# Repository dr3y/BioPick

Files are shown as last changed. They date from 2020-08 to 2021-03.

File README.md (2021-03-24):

# BioPick
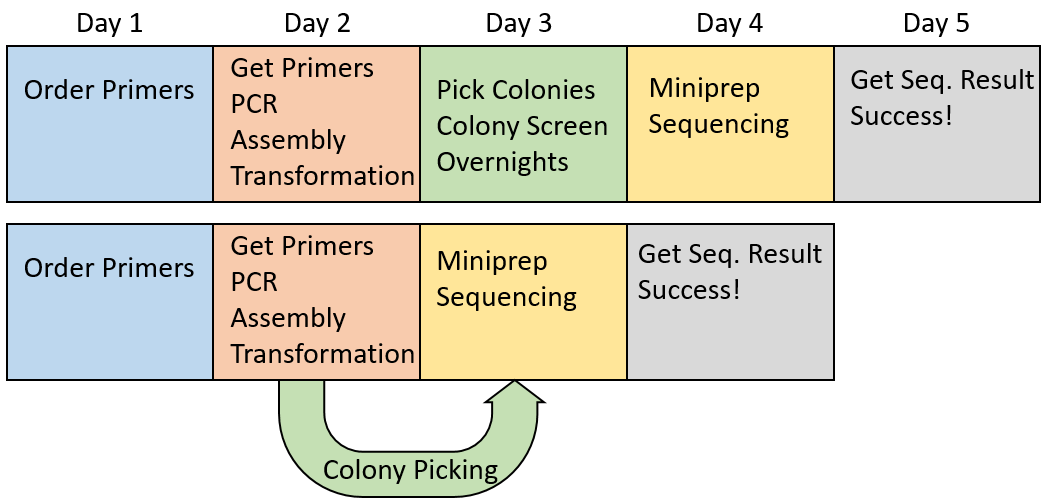
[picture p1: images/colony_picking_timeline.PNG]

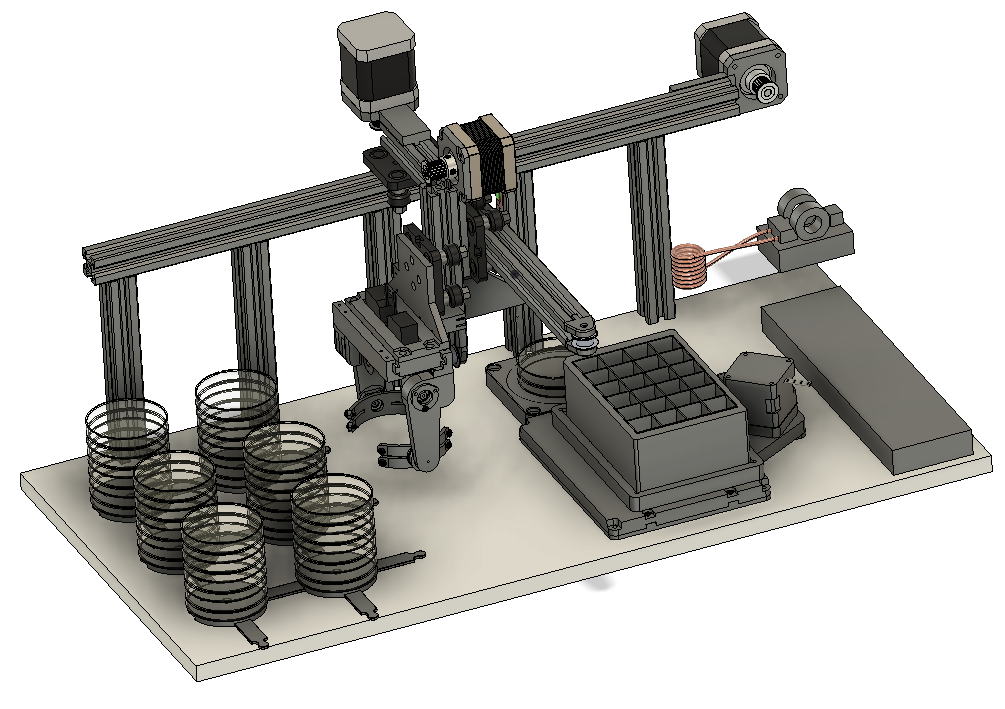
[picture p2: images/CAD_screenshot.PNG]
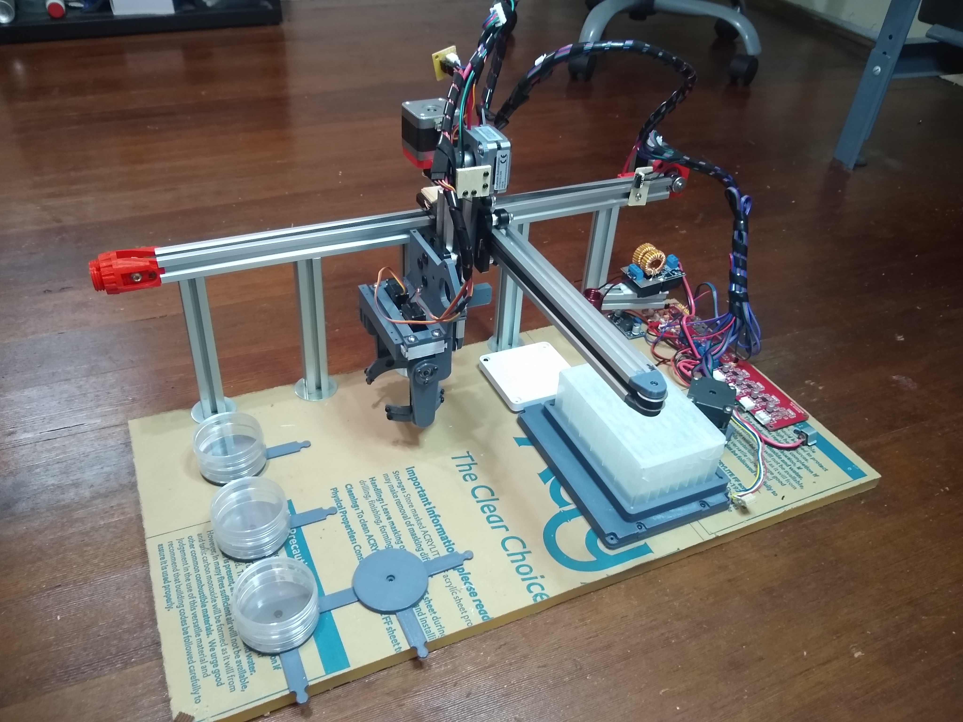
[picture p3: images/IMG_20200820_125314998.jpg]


[video](https://www.youtube.com/watch?v=V8H1xTA8SUk)

BioPick is an open source purpose-built colony picking robot. The idea is to shorten the time from conception to realization of molecular cloning, by allowing automated colony growth and picking as soon as the colonies are grown into liquid culture, to save a day of growth time.
Key features of BioPick are:

1. low profile design
2. multi-plate capacity
3. plate moving and handling capability
4. on board liquid culture shaker
5. metal picking needle that is sterilized by induction heating
6. Off the shelf 3d printer electronics
7. Raspberry Pi camera for colony identification

BioPick is under development so many things can change.
Melzi firmware can be found [here](https://github.com/dr3y/Marlin/tree/Ehoming_test)

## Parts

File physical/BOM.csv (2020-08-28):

name | comment | link | quantity | price | subtotal
V-slot extrusion | 470mm, 310mm, 120mm, 5x140mm | https://www.ebay.com/itm/V-Slot-20x20-Linear-Rail/263747600610 (500mm) | 4 | 5.49
Mini Carriage |  | https://www.amazon.com/Aibecy-Aluminum-Profile-Printer-Accessories/dp/B07SMN97B8/ | 3 | 17.99
inductive heater |  | https://www.amazon.com/Driver-Module-Voltage-Induction-Heating/dp/B01CNM24YM | 1 | 16.7
melzi board | i used a 1.2 board | https://www.amazon.com/MagiDeal-Motherboard-Controller-Mainboard-Control/dp/B0762DXQ8N/ | 1 | 27.99
timing belt and drive pulleys |  | https://www.amazon.com/Zeelo-Timing-Pulley-Meters-Printer/dp/B07XG9JN5B/ | 1 | 12.99
idler pulleys |  | https://www.amazon.com/LICTOP-Aluminum-Timing-Toothless-Printer/dp/B07L9QDVC8 | 1 | 13.99
NEMA17 motor |  | https://www.amazon.com/17HS4401-1-8%C2%B02-Phrase-Universal-Electric-Engraving/dp/B07C1MVTZC/ | 3 | 9.99
low profile NEMA17 motor | i didnt use this one but i think it will work | https://www.amazon.com/Short-Bipolar-Motor-18-4oz-13Ncm/dp/B00PNEQ79Q/ | 1 | 10.99
12g metal gear servo |  | https://www.ebay.com/itm/EMX-SV-0275-EMAX-ES08MAII-12g-Analog-Metal-Gear-Servo/122561614622 | 2 | 9.69
63mm OD 2mm width o ring | you need 1 but 10 come in a pack | https://www.amazon.com/gp/product/B07GJB5WC9 | 1 | 5.49
28mm OD 2mm width o ring | you need 2 but 10 come in a pack | https://www.amazon.com/gp/product/B07GJ9K5JC | 1 | 5.39
5x14x5 bearings | you need 6 bearings but 10 come in a pack | https://www.ebay.com/itm/TRB-RC-5x14x5mm-Precision-Ball-Bearings-ABEC-3-Metal-Shields-10/153903302701 | 1 | 11.12
12v to 5v buck converter | you need 1 but 10 come in a pack | https://www.amazon.com/Zixtec-LM2596-Converter-Module-1-25V-30V/dp/B07VVXF7YX/ | 1 | 13.99
M3 plastite screw set | individual screw amounts will be listed later | https://www.amazon.com/gp/product/B07BTNDC6W | 1 | 15.59
no 2 5/16 plastite screw phillips | you need ~30 but 50 come in a pack | mcmaster | 1 | 4.62
endstop switch | you need 3 but 25 come in a pack | https://www.amazon.com/Cylewet-25Pcs-Switch-Arduino-CYT1073/dp/B073TYWX86/ | 1 | 6.99
stepper motor wires | you need 4 but 10 come in a pack | https://www.amazon.com/UEETEK-Stepper-Connectors-HX2-54-Printer/dp/B06ZZ7SMD7/ | 1 | 14.69
24 awg wire | for endstops and stuff | https://www.amazon.com/22GA-Hook-Wire-Kit-Electrical/dp/B087TJNJZS | 1 | 12.99
dupont connectors | i didnt use this kit i just had some connectors on hand | https://www.amazon.com/Qibaok-Crimping-Ratcheting-Connectors-0-1-0-5mm%C2%B2/dp/B07ZK5F8HP | 1 | 29.99
optical endstop | you need 1 but 6 come in a pack | https://www.amazon.com/HESAI-Printer-Mechanical-Optical-Makerbot/dp/B0719K9Z9R | 1 | 8.99
T nuts and stuff
raspberry pi zero W |  | https://www.amazon.com/gp/product/B075FRRVLR | 1 | 23.99
raspberry pi cam with zero cable |  | https://www.amazon.com/Aokin-Raspberry-Camera-Module-OV5647/dp/B07RXKZ1KN | 1 | 9.59
M3 screws

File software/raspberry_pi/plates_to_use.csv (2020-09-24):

position | name
A1 | plate one
A2 | plate two
A3 | plate three
B1 | plate four

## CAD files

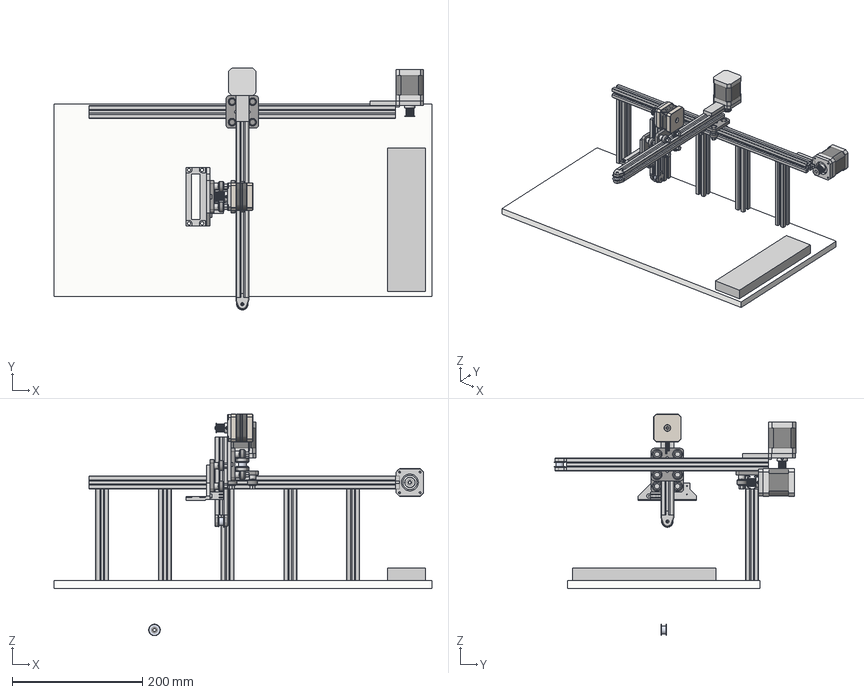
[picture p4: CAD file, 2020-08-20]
physical/frame/colonypicker_assembly_frame.step
580.0 x 371.2 x 340.0 mm
smallcarriage x 3
M4x0.7X5mm - flat-tip Set screw x 6
Nema 17 Stepper Motor x 2
Idler GT2-6 5mm x 3
motor_mount x 2
Nema 17 Stepper Motor length 34mm
Vslot_short x 5
Vslot_long
acrylic base
Vslot_cantilever
Vslot_short (1)
gripper_mount
thinner_motormount
idler_holder x 2
melzi

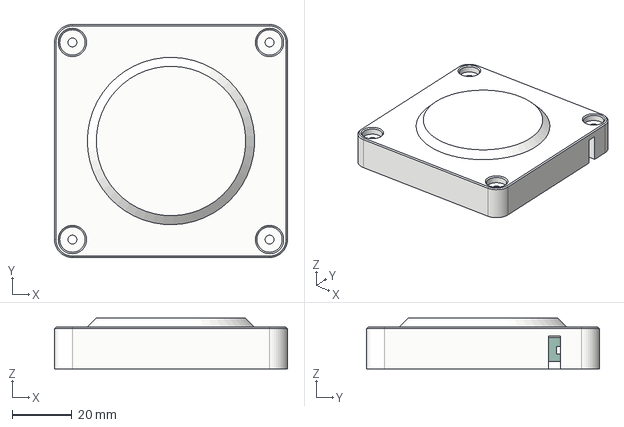
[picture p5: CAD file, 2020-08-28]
physical/backlight/backlight v7.step
78.0 x 78.0 x 17.0 mm

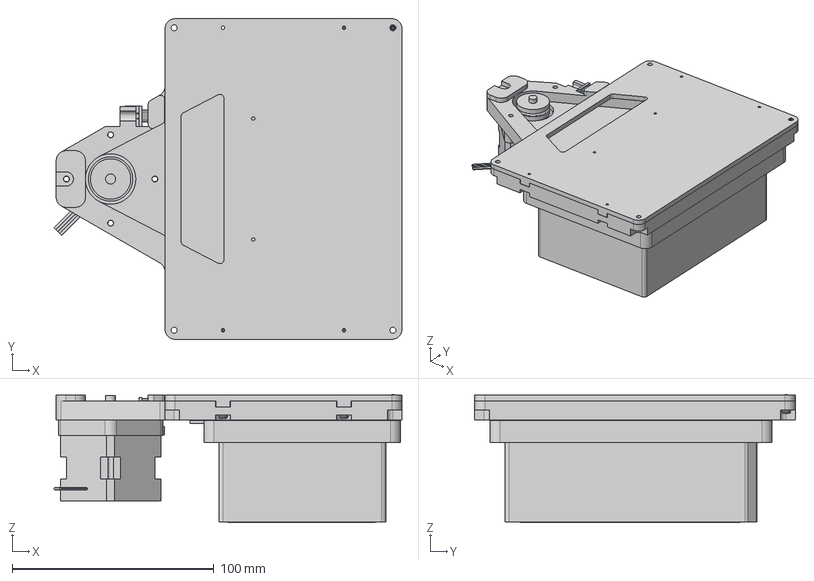
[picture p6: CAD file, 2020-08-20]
physical/culture_shaker/plate_shaker v9.step
172.6 x 159.0 x 63.6 mm
stepper_motor_parametric
24_well_plate
bearing_7804K109 x 2
platform
rotor1
rotor2
rotorcap1
rotorcap2
small_plastite x 6
Optical endstop v3

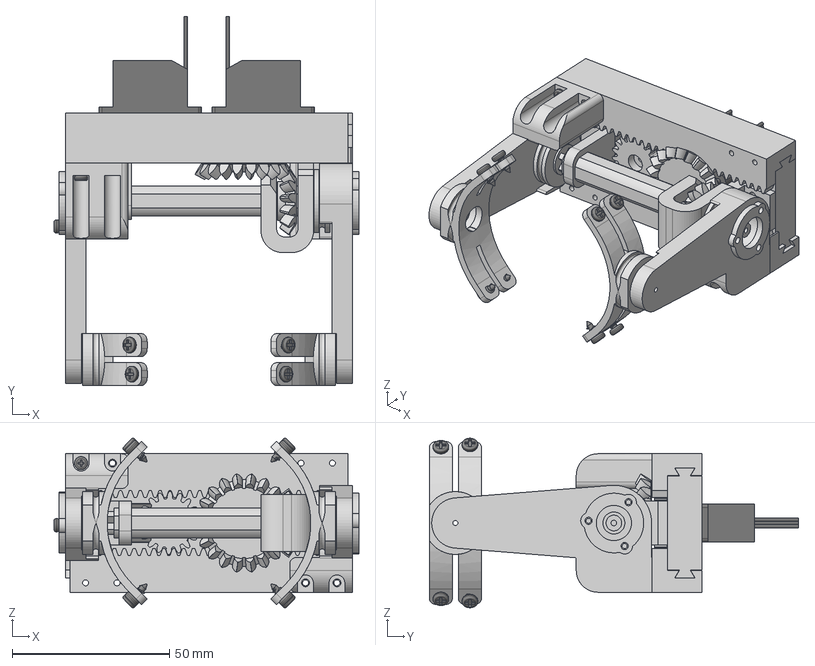
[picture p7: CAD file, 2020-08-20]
physical/gripper/plate_gripper v18.step
97.0 x 117.4 x 54.0 mm
servoholder v5
armMount v1 x 2
emaxservo x 2
gear1
bevelgears_gear2 v1
Spur Gear (18 teeth)
axlemount
bevelholder
arm x 2
bearing_7804K109
small_plastite x 2
hand x 2
outershaftspline
innershaftspline
pointy_screw x 8

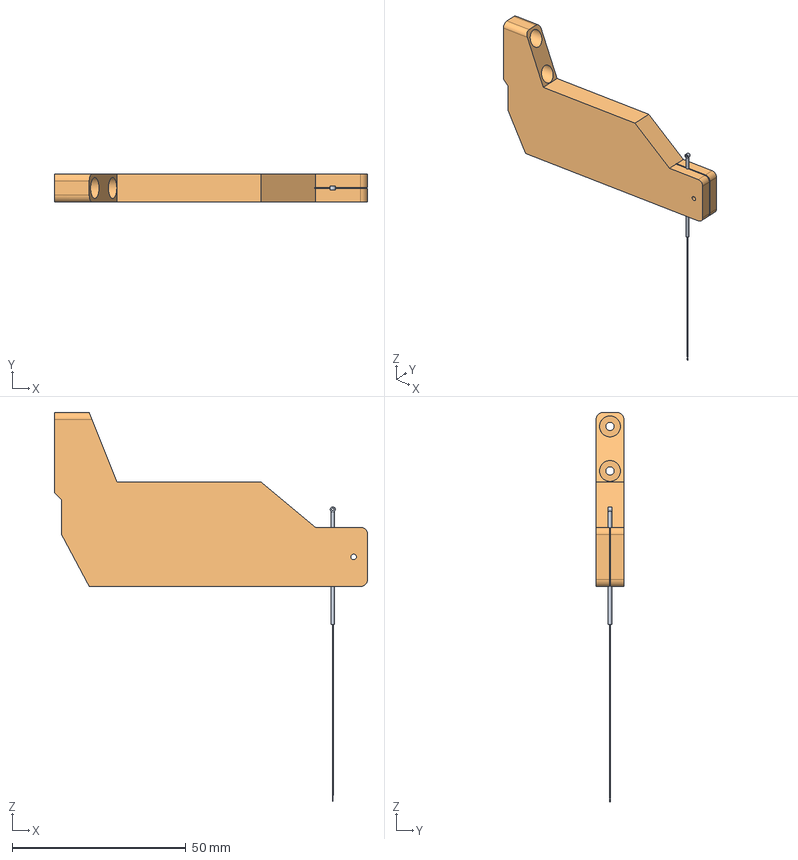
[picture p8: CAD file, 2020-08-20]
physical/needle_holder/needle_holder.step
90.0 x 8.00 x 111.8 mm

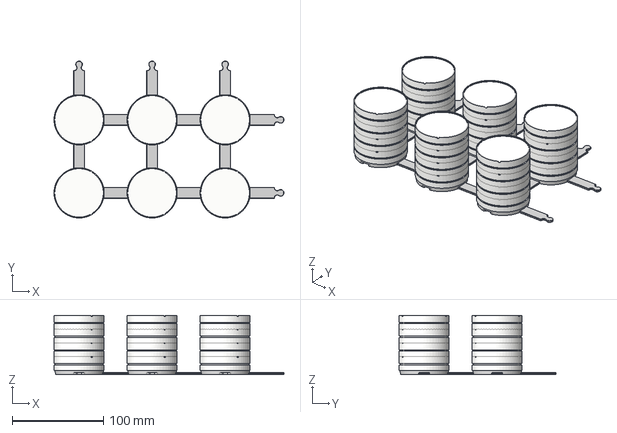
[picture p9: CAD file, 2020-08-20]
physical/plate_organizer/plate_holder.step
252.0 x 172.0 x 64.7 mm
small_petri_dish x 24

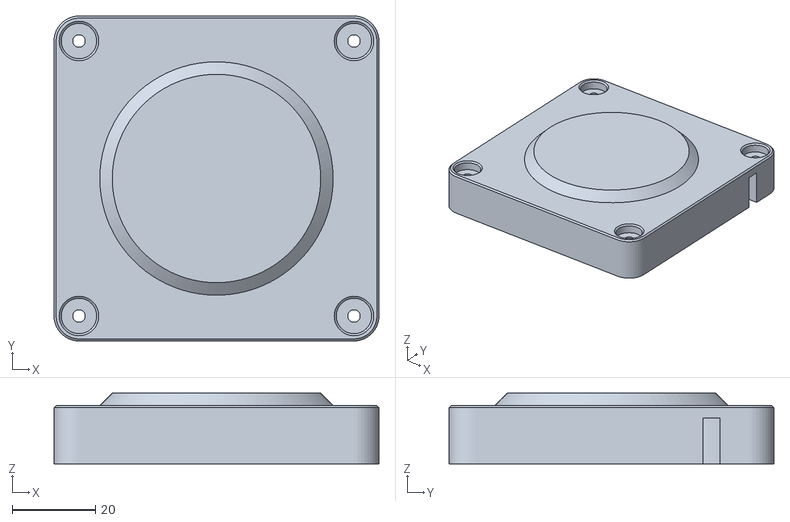
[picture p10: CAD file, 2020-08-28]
physical/stl/backlight/backlight.stl
78.0 x 78.0 x 17.0

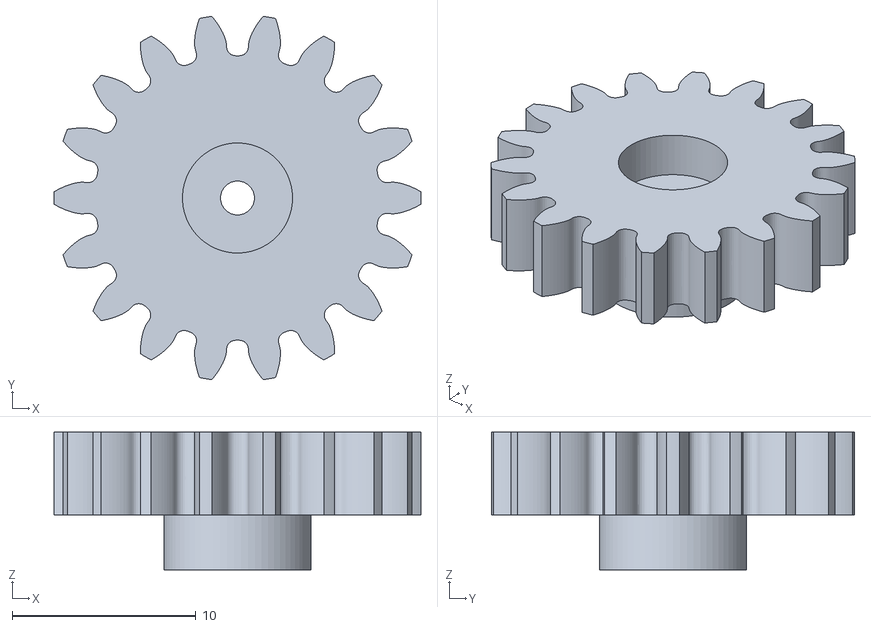
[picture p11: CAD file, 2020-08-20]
physical/stl/gripper/servogear.stl
20.0 x 19.8 x 7.50

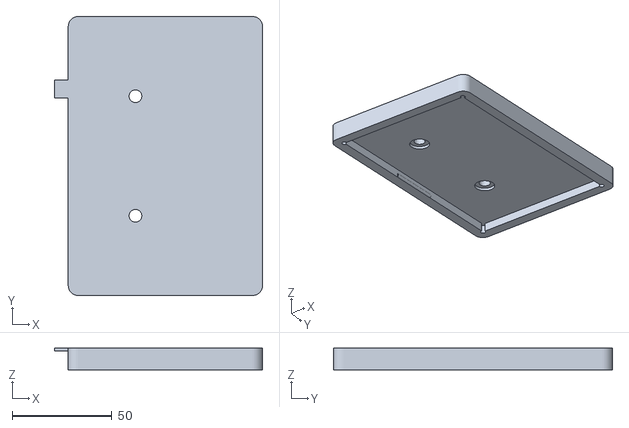
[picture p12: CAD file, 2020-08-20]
physical/stl/plate_shaker/moving_platform.stl
104.4 x 140.0 x 11.0

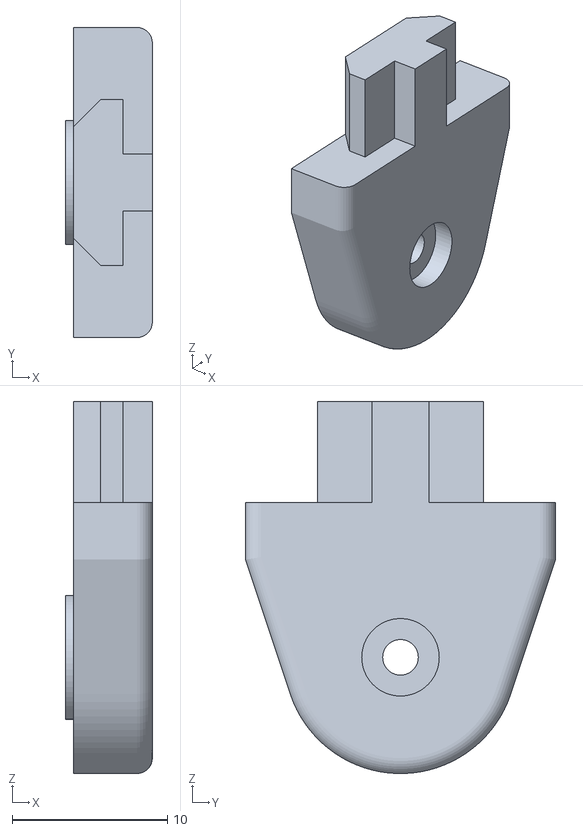
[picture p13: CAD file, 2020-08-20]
physical/stl/frame/idle_holder1.stl
5.60 x 20.0 x 24.0

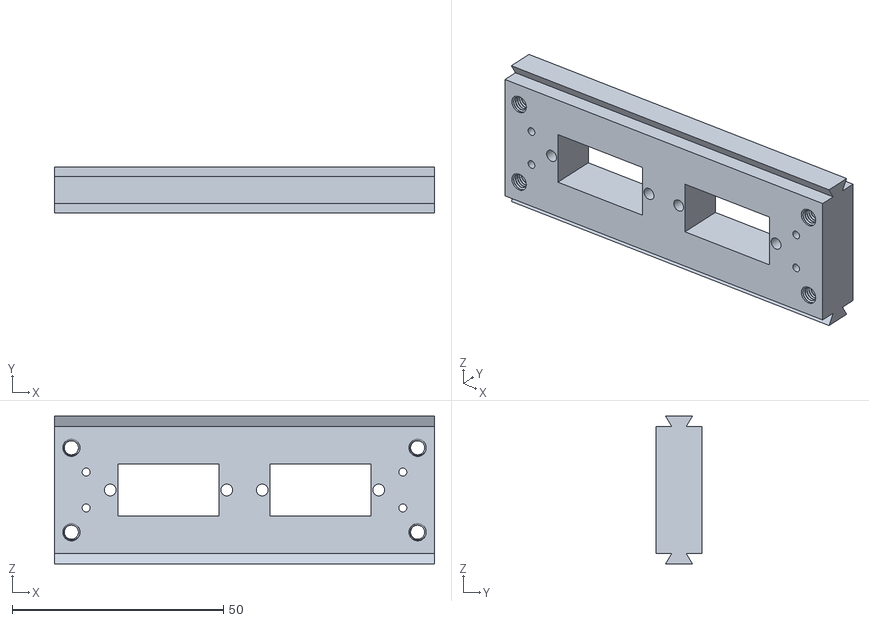
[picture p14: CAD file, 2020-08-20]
physical/stl/gripper/servoholder.stl
90.0 x 11.0 x 35.0

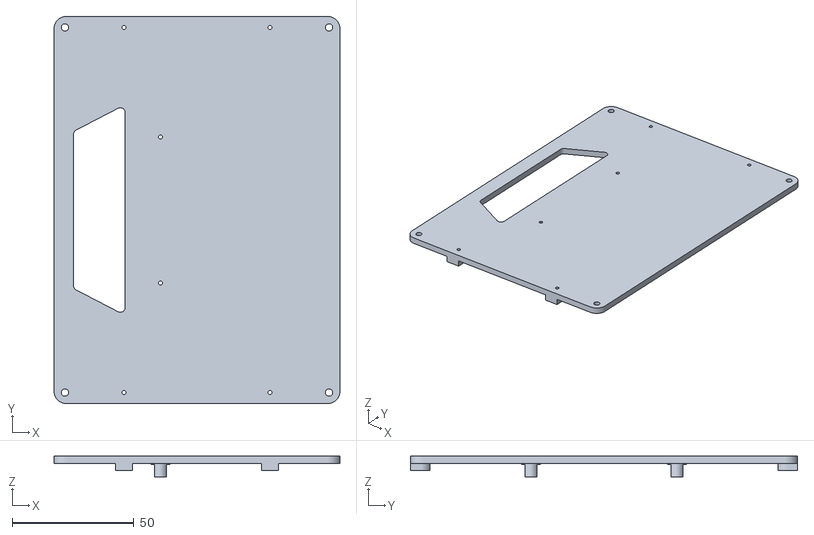
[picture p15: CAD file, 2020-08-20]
physical/stl/plate_shaker/bottom_stator.stl
117.5 x 159.0 x 8.50

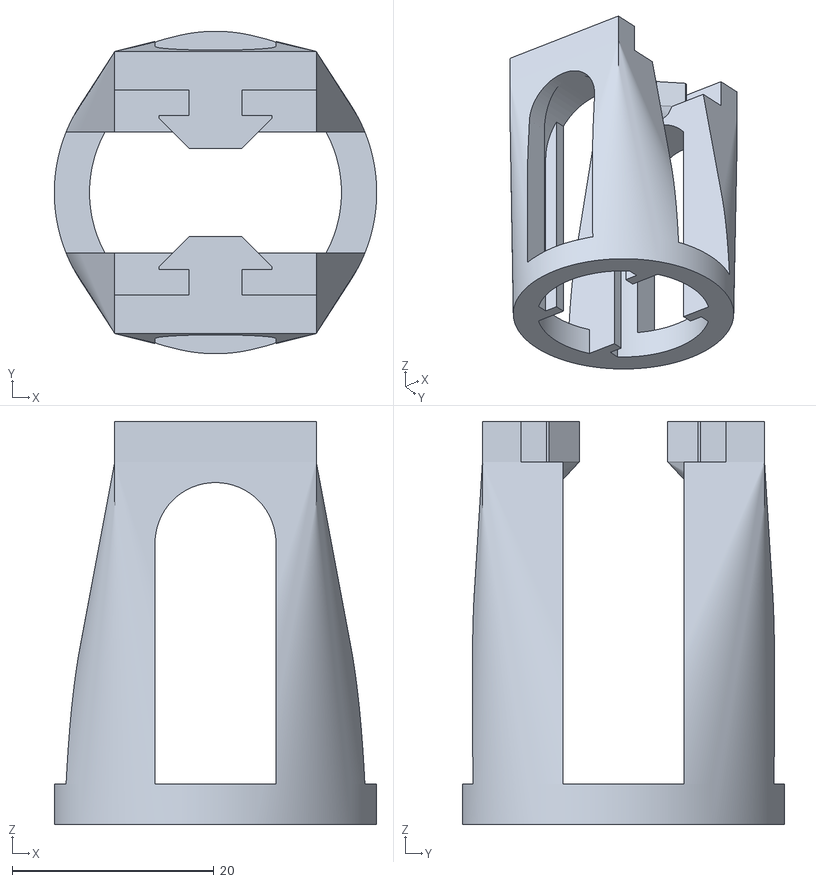
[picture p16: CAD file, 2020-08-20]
physical/stl/frame/fooyabt_r15_case.stl
32.0 x 32.0 x 40.0

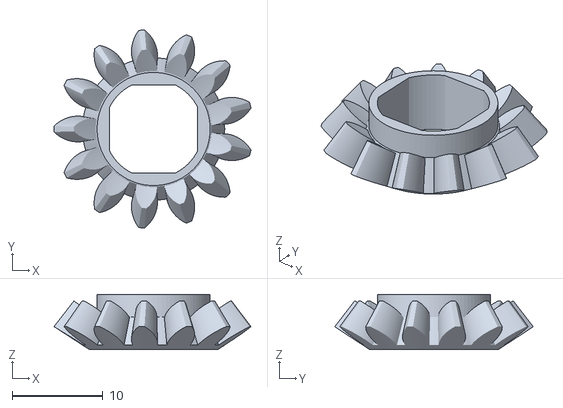
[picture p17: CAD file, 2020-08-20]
physical/stl/gripper/bevelgear_biggerhole.stl
21.8 x 21.9 x 6.08

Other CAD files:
physical/stl/plate_shaker/driver_pulley.stl
physical/stl/frame/idle_holder2.stl
physical/stl/gripper/outershaft_bigger.stl
physical/stl/plate_shaker/top_stator.stl
physical/stl/frame/fooyabt_nut.stl
physical/stl/frame/gripmount.stl
physical/stl/frame/motorholder.stl
physical/stl/frame/y_clamp.stl
physical/stl/gripper/arm.stl
physical/stl/gripper/bearing cover.stl
physical/stl/gripper/bevelmount_biggerhole.stl
physical/stl/gripper/hand.stl
physical/stl/gripper/innershaft_bigger.stl
physical/stl/gripper/largebevelgear.stl
physical/stl/gripper/rack.stl
physical/stl/needle_holder/needleHolder.stl
physical/stl/plate_shaker/medium_washer.stl
physical/stl/plate_shaker/motor_spacer.stl
physical/stl/plate_shaker/rotor_pulley.stl
physical/stl/plate_shaker/small_washer.stl

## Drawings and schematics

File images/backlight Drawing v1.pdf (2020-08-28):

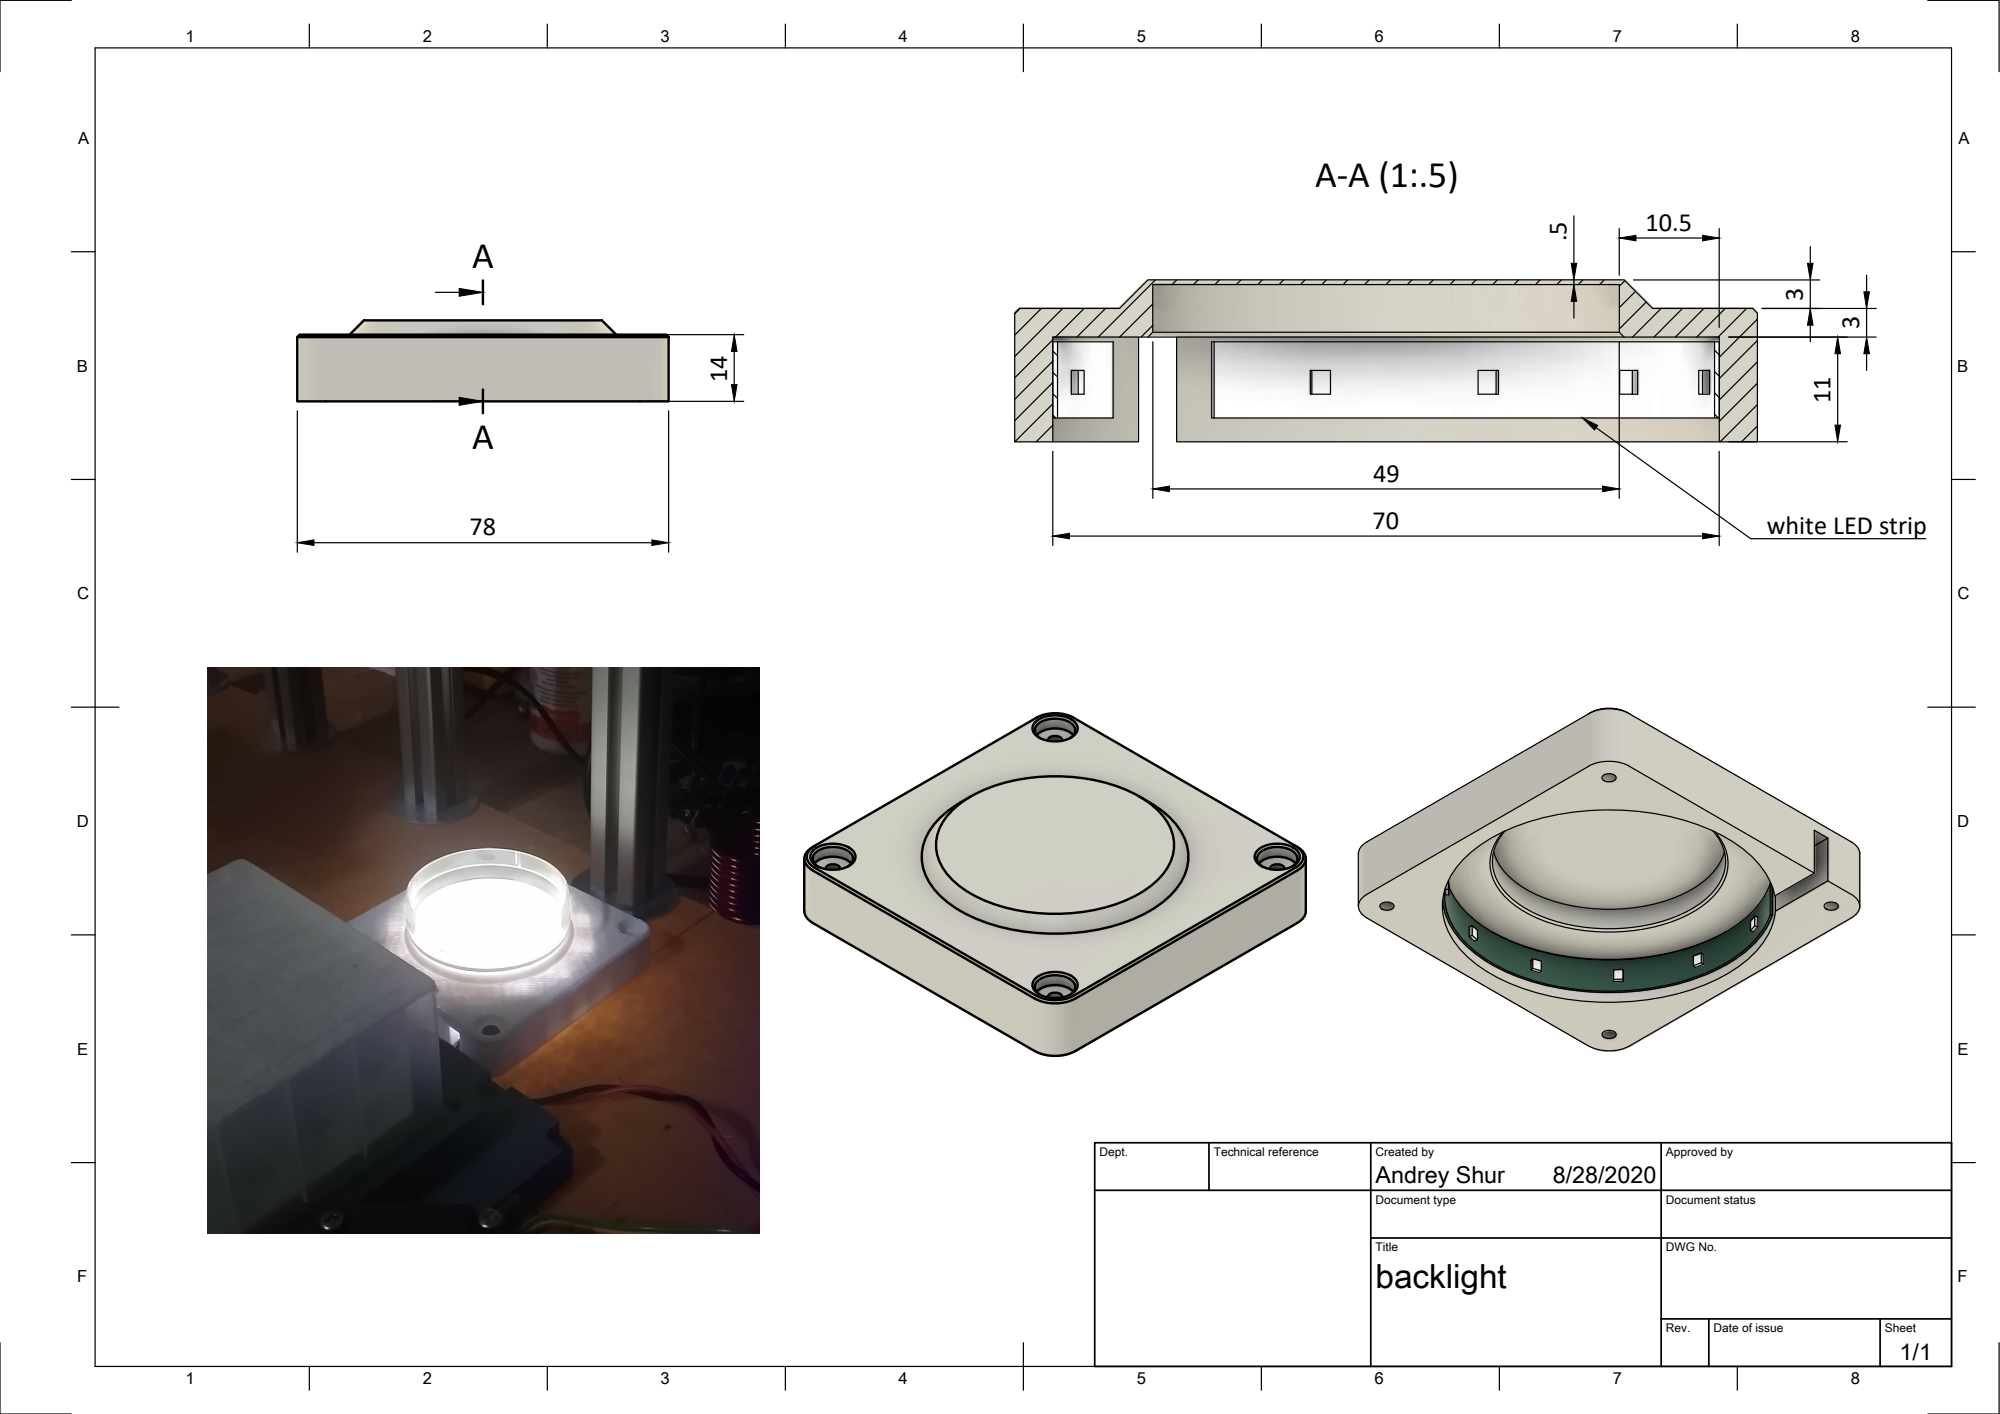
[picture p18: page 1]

white LED strip 14

Dept. | Technical reference | Created by Andrey Shur 8/28/2020 | Approved by

Document type | Document status

Title backlight | DWG No.

Rev. | Date of issue | Sheet 1/1

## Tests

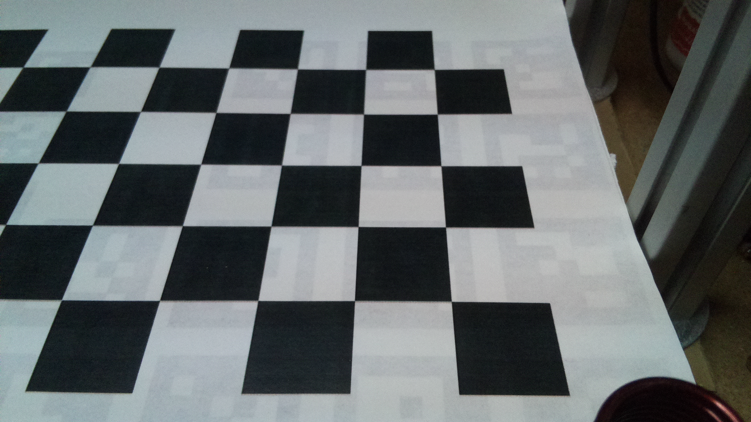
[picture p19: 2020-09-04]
software/raspberry_pi/calibration/calib3.png

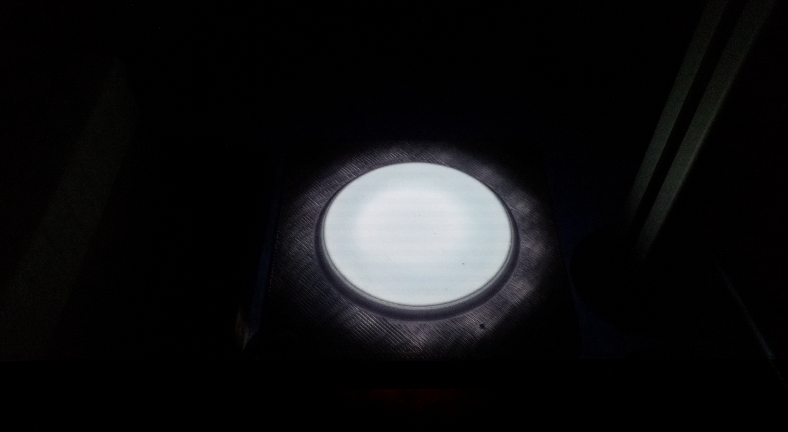
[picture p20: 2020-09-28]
software/raspberry_pi/calibration/lighttable.png

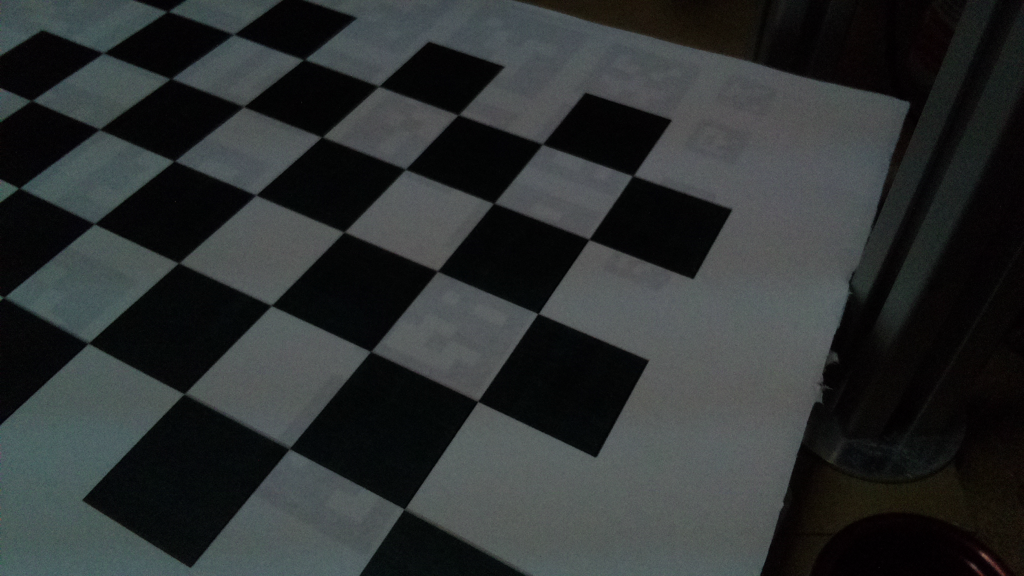
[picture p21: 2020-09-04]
software/raspberry_pi/calibration/calib6.png

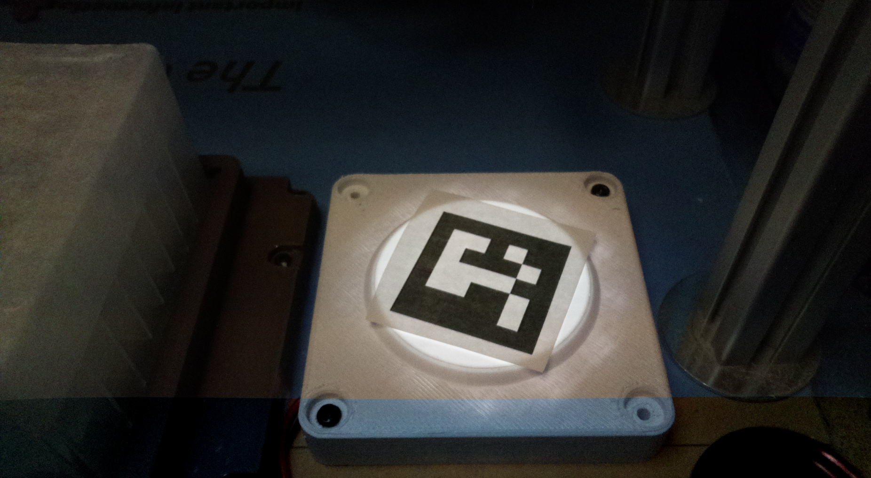
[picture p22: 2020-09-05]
software/raspberry_pi/calibration/aruco3.png

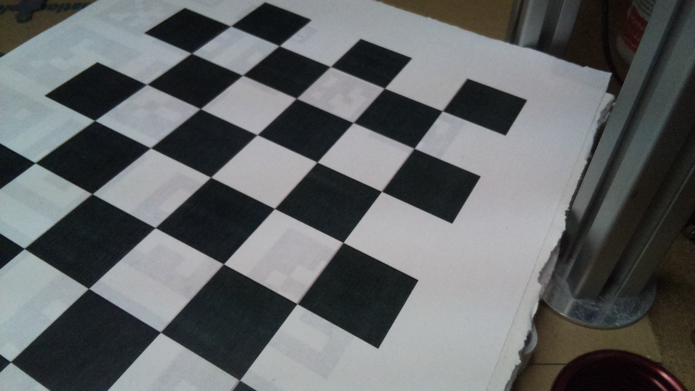
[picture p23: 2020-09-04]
software/raspberry_pi/calibration/calib1.png

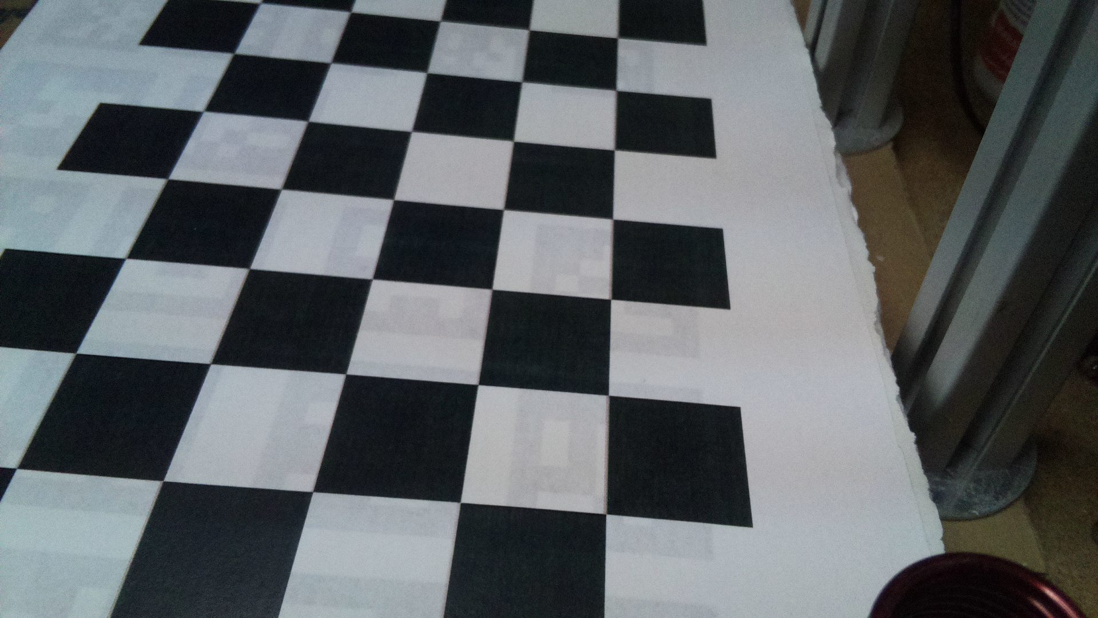
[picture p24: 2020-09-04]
software/raspberry_pi/calibration/calib2.png

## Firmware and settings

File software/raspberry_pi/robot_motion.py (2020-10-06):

import csv
import serial
import time
import robot_gcodes as rcd
import os
#(Robot)

class colonyPicker:
    def __init__(self,plate_dict,culture_plate,robocomm=None,\
                        robobaud=250000,hometimeout = 10,posfile="robot_positions.csv"):
        self.robocomm = robocomm
        self.plate_order = {"C":[3,2,1],"B":[3,2,1],"A":[3,2,1]}
        
        self.culture_plate = culture_plate
        self.plate_dict = plate_dict
        self.robopos = self.load_posfile(posfilename = posfile)
        if(self.robopos is not None):
            self.staging_floors = sorted(list(self.robopos["plate_staging"].keys()))
        else:
            self.staging_floors = None
        self.robocomm = None
        self.hometimeout = hometimeout #number of minutes without action before you need to home again
        self.lasthomed = -hometimeout
        if(robocomm is not None):
            self.robocomm = serial.Serial(robocomm,robobaud,timeout=5)
            time.sleep(8)
            _=self.read_till_ok(empty_is_ok=True)
        #plate dict looks something like this: 
        #{"A1":"testconstruct1","A2":"con2_2"}
        #numbers are the plate position, strings are the names of the plates
        #TODO: validate plate dict
    @classmethod
    def load_posfile(cls,posfilename):
        posdict = {}
        with open(posfilename) as csv_file:
            csv_reader = csv.reader(csv_file, delimiter=',')
            line_count = 0
            colnames = []
            for row in csv_reader:
                if line_count == 0:
                    colnames = row
                    #print(f'Column names are {", ".join(row)}')
                else:
                    posname = row[0]
                    locname = row[1]
                    locdict = {locname:{}}
                    if(row[3]==""):
                        posx = None
                    else:
                        posx = float(row[3])
                        locdict[locname]["X"]=posx
                    if(row[4]==""):
                        posy=None
                    else:
                        posy = float(row[4])
                        locdict[locname]["Y"]=posy
                    if(row[5]==""):
                        posz=None
                    else:
                        posz = float(row[5])
                        locdict[locname]["Z"]=posz
                    if(row[6]==""):
                        pose = None
                    else:
                        pose = float(row[6])
                        locdict[locname]["E"]=pose
                    if(row[7]==""):
                        s0pos = None
                    else:
                        s0pos = float(row[7])
                        locdict[locname]["S0pos"]=s0pos
                    if(row[8]==""):
                        s1pos = None
                    else:
                        s1pos = float(row[8])
                        locdict[locname]["S1pos"]=s1pos
                    if(posname in posdict):
                        posdict[posname].update(locdict)
                    else:
                        posdict[posname] = locdict

                line_count += 1
        return posdict
    def read_till_ok(self,alternative_ending=None,empty_is_ok=False):
        if(self.robocomm is None or not self.robocomm.is_open):
            print("Robot is not connected")
            return
        readtext = ""
        while True:
            x = str(self.robocomm.readline())[2:-1]
            readtext += x
            if("ok" in x):
                return readtext
            elif((alternative_ending is not None )and (alternative_ending in x)):
                return readtext
            elif(x==""):
                if(not empty_is_ok):
                    print("== NO OK RECIEVED ==")
                    raise serial.SerialException("no ok recieved")
                else:
                    return readtext
        
    def send_gcode_multiline(self,gcode_list,retval="\n"):
        for gcode_line in gcode_list:
            if(retval not in gcode_line):
                self.robocomm.write(bytes(gcode_line+retval, 'utf-8'))
                self.robocomm.flush()
                machine_output=self.read_till_ok()
            else:
                gsplit = gcode_line.split(retval)
                for subline in gsplit:
                    self.robocomm.write(bytes(subline+retval, 'utf-8'))
                    self.robocomm.flush()
                    machine_output=self.read_till_ok()
        return machine_output
    def home(self):
        self.send_gcode_multiline(rcd.gcode_home())
    #TODO def get_current_pos(self):
    #    pos_output = self.send_gcode_multiline(["M114"])
    #    for sline in pos_output.split("\\n"):
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

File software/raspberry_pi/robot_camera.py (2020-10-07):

import numpy as np
import cv2
try:
    from picamera import PiCamera
    from picamera.array import PiRGBArray
    CAMERA_ACTIVE = True
except ModuleNotFoundError:
    CAMERA_ACTIVE = False
import pickle
import glob
import os
import time
import peakutils.peak
from IPython.display import Image

def show_image(img):
    cv2.imwrite('testimage.png',img)
    display(Image(filename="testimage.png"))
def smooth(y, box_pts):
    box = np.ones(box_pts)/box_pts
    y_smooth = np.convolve(y, box, mode='same')
    return y_smooth
class robo_camera:
    def __init__(self,resolution="1920x1080",shutter_speed=2000,camera_matrix="camera_matrix.pckl"):
        self.mtx = None
        self.dist = None
        self.cam_calibrated = False
        if(camera_matrix is not None):
            pickfle = open(camera_matrix, "rb")
            mtx,dist = pickle.load(pickfle)
            self.mtx = mtx
            self.dist = dist
            self.cam_calibrated = True
        if(CAMERA_ACTIVE):
            self.camera = PiCamera()
            self.camera.resolution = resolution
            self.camera.shutter_speed = 2000
    def init_blob_detector(self,mint=130,maxt=500,mina=27,maxa=130,mincir=0.9,mincon=0.95,minin=.8):
        #################BLOB DETECTOR###############
        params = cv2.SimpleBlobDetector_Params()
        # Change thresholds
        params.minThreshold = mint
        params.maxThreshold = maxt

        # Filter by Area.
        params.filterByArea = True
        params.minArea = mina
        params.maxArea = maxa

        # Filter by Circularity
        params.filterByCircularity = True
        params.minCircularity = mincir

        # Filter by Convexity
        params.filterByConvexity = True
        params.minConvexity = mincon

        # Filter by Inertia
        params.filterByInertia = True
        params.minInertiaRatio = minin

        # Create a detector with the parameters
        detector = cv2.SimpleBlobDetector_create(params)
        return detector
    def detect_colonies(self,impath,image_transform,vector_transform,display_image=False,save_image=True,\
                                            mint=130,maxt=500,mina=27,maxa=130,mincir=0.9,mincon=0.95,minin=.8):
        img = cv2.imread(os.path.join('.','pictures',impath))
        x = time.localtime()
        tstamp = str(x.tm_year)[2:]+str(x.tm_mon)+str(x.tm_mday)+str(x.tm_hour)+str(x.tm_min)
        colonypick_path = os.path.join('.','pictures',str(tstamp+'_picked_'+impath))

        #this next part warps the image so that it is rectified and in the middle of the frame
        transform = image_transform
        warp = cv2.warpPerspective(img,transform,(500,550)) #transforming the calibrated image
        warp_gray = cv2.cvtColor(warp,cv2.COLOR_BGR2GRAY)
        #making a mask for colony finding
        warp_empty = np.zeros(shape=[550, 500, 1], dtype=np.uint8)
        center_coordinates = (230, 250) 
        axesLength = (170, 140) 
        warp_colony_mask = cv2.ellipse(warp_empty,center_coordinates,axesLength,0,0,360,255,-1)
        warp_gray_inv = 255-warp_gray
        warp_blur = cv2.GaussianBlur(warp_gray_inv,(101,101),50,borderType=cv2.BORDER_DEFAULT)
        #background subtraction
        colony_nobg = cv2.subtract(warp_gray_inv,warp_blur)
        colony_crop = (255-cv2.bitwise_and(colony_nobg, colony_nobg, mask=warp_colony_mask))*4
        #colony_crop = colony_crop.convertTo(colony_crop,cv2.CV_8U)
        maxval = np.max(colony_crop) #maximum pixel value in the image
        minval = np.min(colony_crop) #minimum pixel value in the image

        gaus = cv2.adaptiveThreshold(colony_crop, 255, cv2.ADAPTIVE_THRESH_GAUSSIAN_C, cv2.THRESH_BINARY, 91, 12)
        
        gaus_eroded = cv2.dilate(gaus,np.ones([3,3]),iterations=1)
        gaus_eroded = cv2.erode(gaus_eroded,np.ones([3,3]),iterations=1)
        #gaus_eroded = gaus
        #cv2.imwrite('testimage.png',gaus_eroded)
        #display(Image('testimage.png'))


        detector = self.init_blob_detector(mint=mint,maxt=maxt,mina=mina,maxa=maxa,mincir=mincir,mincon=mincon,minin=minin)
        #blob detection
        keypoints = detector.detect(gaus_eroded)
        #print(keypoints)
        print(len(keypoints))        
        warp_with_keypoints = cv2.drawKeypoints(warp, keypoints,\
                        np.array([]), 255, cv2.DRAW_MATCHES_FLAGS_DRAW_RICH_KEYPOINTS)
        if(save_image):
            cv2.imwrite(colonypick_path, warp_with_keypoints)
            if(display_image):
                display(Image(filename=colonypick_path))
        elif(display_image):
            cv2.imwrite("testimage.png", warp_with_keypoints)
            display(Image(filename="testimage.png"))
        imstripe = warp[30:110, 215:235]
        imstripe_gray = cv2.cvtColor(imstripe, cv2.COLOR_BGR2GRAY)
        im_trace = np.mean(imstripe_gray, axis=1)
        im_deriv = smooth(-np.gradient(im_trace, 10), 4)
        im_base = peakutils.baseline(im_deriv, 2)
        im_deriv_debased = im_deriv-im_base

        highs = peakutils.peak.indexes(
            im_deriv_debased,
            thres=1/max(im_deriv_debased), min_dist=20
        )
        filteredhighs = []
        for high in highs:
            if(high >15 and high < 70):
                filteredhighs += [high]
        high_data = []
        for high in filteredhighs:
            yval = im_deriv_debased[high]
            high_data += [[yval,high]]
        #plt.plot([a[1] for a in high_data],[a[0] for a in high_data],'o')
        if(len(filteredhighs) != 2):
            agar_to_rim_distance = 34 #default assumption
        else:
            agar_to_rim_distance = filteredhighs[1]-filteredhighs[0]
        
        #print("agar to rim distance is "+str(agar_to_rim_distance))
        return keypoints
    def capture(self,savepath=None):
        if(not CAMERA_ACTIVE):
            return None
        rawCapture = PiRGBArray(self.camera)
        self.camera.capture(rawCapture,format="bgr")
        img = rawCapture.array
        if(self.cam_calibrated):
            #undistort the camera if it is calibrated
            h,  w = img.shape[:2]
            newcameramtx, roi=cv2.getOptimalNewCameraMatrix(self.mtx,self.dist,\
                                                                (w,h),1,(w,h))
            dst = cv2.undistort(img, self.mtx, self.dist, None, newcameramtx)
            x,y,w,h = roi
            dst = dst[y:y+h, x:x+w]
            img = dst
        if(savepath is not None):
            #save it if that is desired
            cv2.imwrite(savepath,img)
        return img
    def mask_lit_background(self,bg_image = None):
        if(bg_image is None):
            bg_image = self.capture()
        bgimg_gray = cv2.cvtColor(bg_image,cv2.COLOR_BGR2GRAY)
        #bg_subtractor = cv2.createBackgroundSubtractorMOG2()
        #fgmask = bg_subtractor.apply(bgimg_gray) #the first image is the background
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

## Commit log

2020-08-20 physical files and pics
    [arm.stl, backlight v2.step, backlight.stl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]
2020-08-20 changed picture to CAD screenshot
2020-08-28 backlight drawing and starting robot motion code
    [BOM.csv, backlight v7.step, backlight.stl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]
2020-08-29 working serial comm and motion macros
    [robot_positions.csv]
2020-09-01 repeatability test
    [robot_positions.csv]
2020-09-01 conditional plate flipping
2020-09-02 camera resolution
2020-09-02 remove sensor mode setting
2020-09-04 camera calibration and undistortion
2020-09-04 reset staging floors every time
    [plate_repeatability_script.py]
2020-09-04 reset rawcapture every time
    [plate_repeatability_script.py]
2020-09-04 camera file and reading in plate positions
    [plates_to_use.csv]
2020-09-05 camera transformation experiments
2020-09-14 test images and plate height experiments
2020-09-21 updated positions
    [robot_positions.csv, robot_positons_old.csv]
2020-09-21 position typo
    [robot_positions.csv]
2020-09-24 new positions
    [robot_positions.csv]
2020-09-24 new plate pics
    [plates_to_use.csv]
2020-09-28 automated calibration and transformation
2020-09-28 updated calibration images
2020-09-29 lower A1 and staging by 0.5 mm
    [robot_positions.csv]
2020-10-06 notebook service and better calibration
2020-10-07 slight reformat of playing with camera
